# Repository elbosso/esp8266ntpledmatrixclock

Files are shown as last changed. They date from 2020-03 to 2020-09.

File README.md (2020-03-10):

# esp8266ntpledmatrixclock

<!---
[![start with why](https://img.shields.io/badge/start%20with-why%3F-brightgreen.svg?style=flat)](http://www.ted.com/talks/simon_sinek_how_great_leaders_inspire_action)
--->










This repository actually combines what i learned from building
https://github.com/elbosso/sonoffSocket
and 
https://github.com/elbosso/esp8266epaperdoorsign
with an MAX7119 8x8 Led Matrix (well - actually four of them) and
a photo resistor.

The data for connecting with your wifi is located in a header file named `wifi_security.h` that i did
not commit for obvious reasons. Its contents look something like the contents of the example named
`wifi_security_h.example`:

```
#ifndef WIFISECURITY_H
#define WIFISECURITY_H

char wifi_ssid[]="<wifi_ssid>";
char wifi_pwd[]="<wifi_pwd>";
char wifi_ssid_cell_ap[]="<wifi_ssid_cell_ap>";
char wifi_pwd_cell_ap[]="<wifi_pwd_cell_ap>";

#endif /* WIFISECURITY_H */
```

The define `AT_HOME` is used to control what NTP-server should be used: The source code presumes a local NTP-server 
exists at IP-address `192.168.10.2` if
`AT_HOME` is set to 1 - if this is not so, it currently asks `2.de.pool.ntp.org` for the time.

The define `AT_HOME` also decides which pair of WIFI credentials are to be used.

Instructions for setting up the arduino IDE to actually be able to transfer the code to a Wemos D1 (clone) can be found [here](https://averagemaker.com/2018/03/wemos-d1-mini-setup.html)

And so we have a nifty little clock...

## Important Update

This project continues the work originally started in this project: https://github.com/elbosso/ESP8266-WiFi-Marquee

The new features include:

* offering a HTTP interface for specifying arbitrary text that is displayed using running text
* offering an MQTT interface for the same reasons
* allowing to switch the display of the time on and off both via HTTP and MQTT
* possibility to use arbitrarily many chained display modules

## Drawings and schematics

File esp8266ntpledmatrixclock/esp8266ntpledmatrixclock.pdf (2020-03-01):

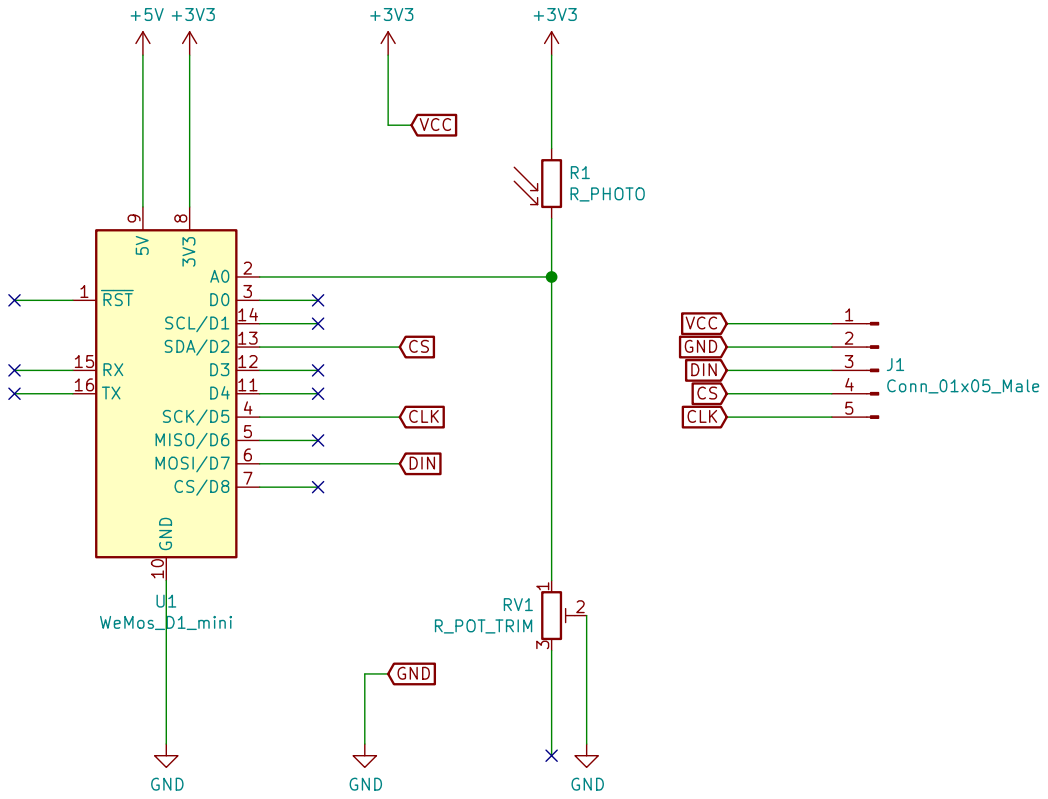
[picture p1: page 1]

File: esp8266ntpledmatrixclock.sch Sheet: / GND

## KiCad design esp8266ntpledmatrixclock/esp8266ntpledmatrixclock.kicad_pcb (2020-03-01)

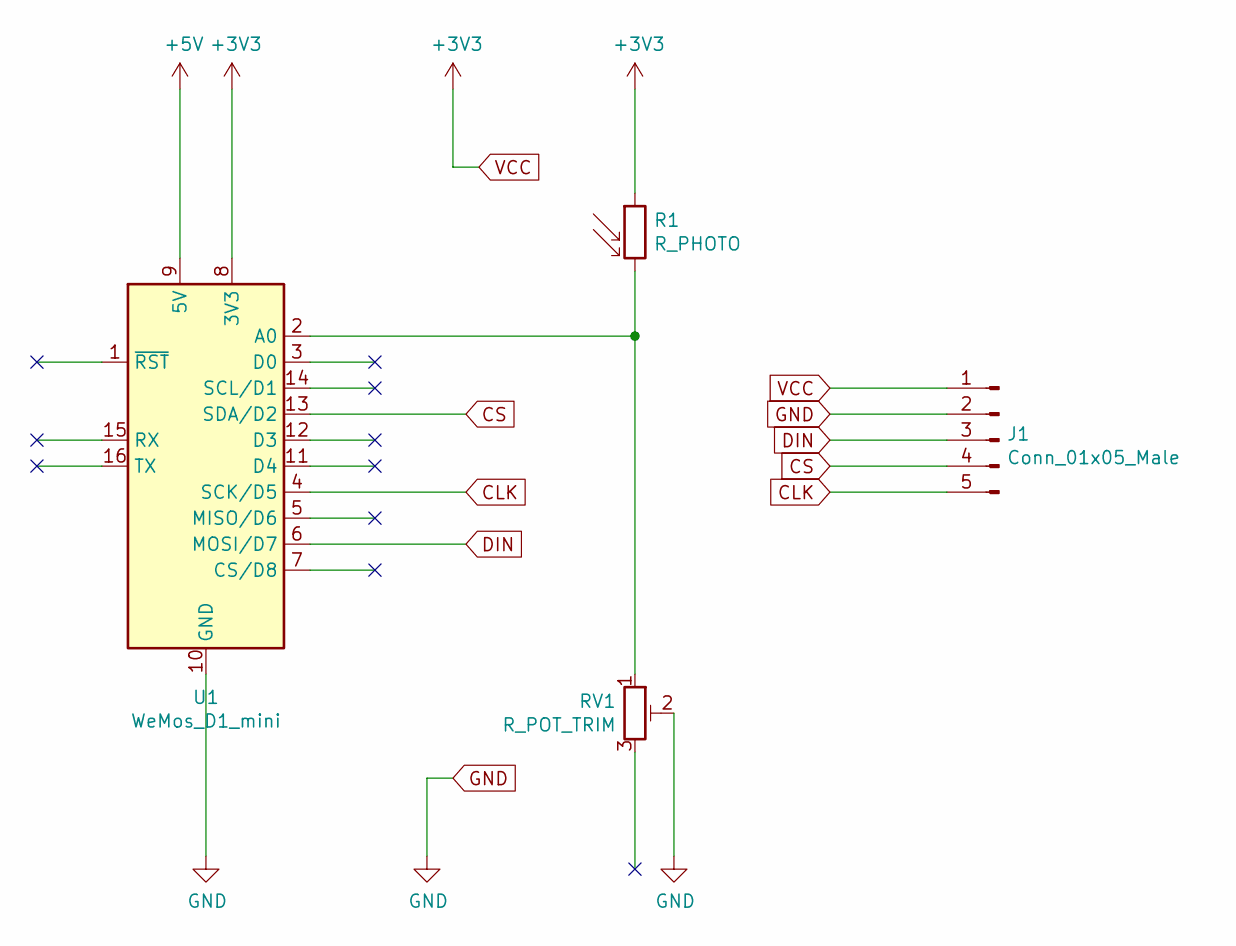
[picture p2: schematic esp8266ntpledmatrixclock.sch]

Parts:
J1: Conn_01x05_Male; PinHeader_1x05_P2.54mm_Vertical
R1: R_PHOTO; R_Axial_DIN0309_L9.0mm_D3.2mm_P12.70mm_Horizontal
RV1: R_POT_TRIM; Potentiometer_Bourns_3386F_Vertical
U1: WeMos_D1_mini; WEMOS_D1_mini_light

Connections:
+5V: U1.9 (5V)
CLK: J1.5, U1.4 (SCK/D5)
CS: J1.4, U1.13 (SDA/D2)
DIN: J1.3, U1.6 (MOSI/D7)
GND: J1.2, RV1.2, U1.10 (GND)
unnamed: R1.2, RV1.1, U1.2 (A0)
VCC: J1.1, R1.1, U1.8 (3V3)

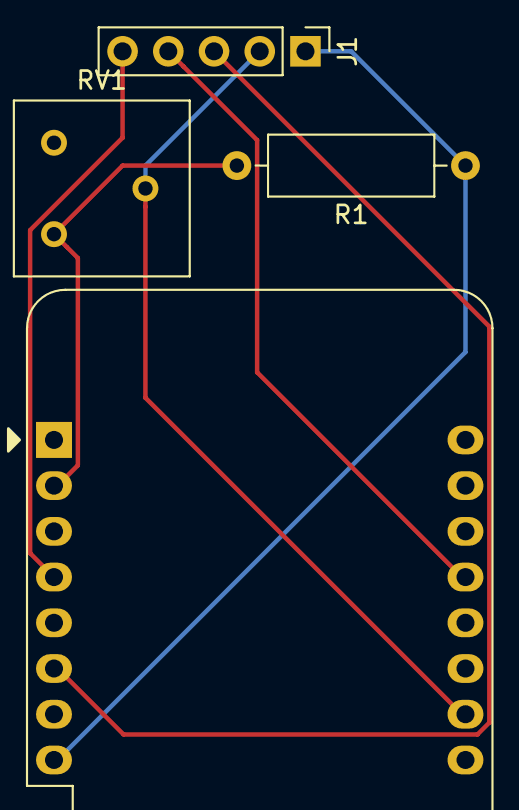
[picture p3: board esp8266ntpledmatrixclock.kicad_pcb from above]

Board: 2 copper layers, 4 parts (0 on the bottom side), 6 nets.

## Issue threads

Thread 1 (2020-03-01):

daisy-chain more than one display and make it possible to display short messages via mqtt or http

elbosso, 2020-03-01:

elbosso, 2020-03-10:
done!

Closed 2020-03-10.

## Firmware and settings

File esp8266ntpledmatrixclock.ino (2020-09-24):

/*
  Copyright (c) 2018.

  Juergen Key. Alle Rechte vorbehalten.

  Weiterverbreitung und Verwendung in nichtkompilierter oder kompilierter Form,
  mit oder ohne Veraenderung, sind unter den folgenden Bedingungen zulaessig:

   1. Weiterverbreitete nichtkompilierte Exemplare muessen das obige Copyright,
  die Liste der Bedingungen und den folgenden Haftungsausschluss im Quelltext
  enthalten.
   2. Weiterverbreitete kompilierte Exemplare muessen das obige Copyright,
  die Liste der Bedingungen und den folgenden Haftungsausschluss in der
  Dokumentation und/oder anderen Materialien, die mit dem Exemplar verbreitet
  werden, enthalten.
   3. Weder der Name des Autors noch die Namen der Beitragsleistenden
  duerfen zum Kennzeichnen oder Bewerben von Produkten, die von dieser Software
  abgeleitet wurden, ohne spezielle vorherige schriftliche Genehmigung verwendet
  werden.

  DIESE SOFTWARE WIRD VOM AUTOR UND DEN BEITRAGSLEISTENDEN OHNE
  JEGLICHE SPEZIELLE ODER IMPLIZIERTE GARANTIEN ZUR VERFUEGUNG GESTELLT, DIE
  UNTER ANDEREM EINSCHLIESSEN: DIE IMPLIZIERTE GARANTIE DER VERWENDBARKEIT DER
  SOFTWARE FUER EINEN BESTIMMTEN ZWECK. AUF KEINEN FALL IST DER AUTOR
  ODER DIE BEITRAGSLEISTENDEN FUER IRGENDWELCHE DIREKTEN, INDIREKTEN,
  ZUFAELLIGEN, SPEZIELLEN, BEISPIELHAFTEN ODER FOLGENDEN SCHAEDEN (UNTER ANDEREM
  VERSCHAFFEN VON ERSATZGUETERN ODER -DIENSTLEISTUNGEN; EINSCHRAENKUNG DER
  NUTZUNGSFAEHIGKEIT; VERLUST VON NUTZUNGSFAEHIGKEIT; DATEN; PROFIT ODER
  GESCHAEFTSUNTERBRECHUNG), WIE AUCH IMMER VERURSACHT UND UNTER WELCHER
  VERPFLICHTUNG AUCH IMMER, OB IN VERTRAG, STRIKTER VERPFLICHTUNG ODER
  UNERLAUBTE HANDLUNG (INKLUSIVE FAHRLAESSIGKEIT) VERANTWORTLICH, AUF WELCHEM
  WEG SIE AUCH IMMER DURCH DIE BENUTZUNG DIESER SOFTWARE ENTSTANDEN SIND, SOGAR,
  WENN SIE AUF DIE MOEGLICHKEIT EINES SOLCHEN SCHADENS HINGEWIESEN WORDEN SIND.
*/

#define AT_HOME 1
#define REGELBETRIEB 1

#include <FS.h> //this needs to be first, or it all crashes and burns...

#include <ESP8266WiFi.h>
#include <WiFiClient.h>
#include <ESP8266WebServer.h>
#include <ESP8266mDNS.h>
#include <WiFiUdp.h>
//needed for wifimanager
#include <DNSServer.h>
#include <WiFiManager.h>          //https://github.com/tzapu/WiFiManager
#include <PubSubClient.h>
#include "RemoteDebug.h"  //https://github.com/JoaoLopesF/RemoteDebug

//
// Debug messages over the serial console.
//
#include "debug.h"

#include <NTPClient.h>
#include <WiFiUdp.h>
#include <TimeLib.h>
#include <Timezone.h>    // https://github.com/JChristensen/Timezone
#include <stdio.h>
#include <user_interface.h>
#include <ArduinoJson.h>          // https://github.com/bblanchon/ArduinoJson
#include <LEDMatrixDriver.hpp>
#include "wifi_security.h"
#include "clock_font.h"
#include "marquee_font.h"
#include "marquee_font1.h"
#include "marquee_form.h"

/**
  Random Number Generator 32bit
  http://esp8266-re.foogod.com/wiki/Random_Number_Generator
 **/
#define RANDOM_REG32  ESP8266_DREG(0x20E44)
 
//ESP8266WebServer* server;
ESP8266WebServer marqueeserver(8080);  // HTTP server will listen at port 8080

bool lamp = 0;

char port[6] = "80";

//flag for saving data
bool shouldSaveConfig = false;

int gpio0Switch = 5;

unsigned long previousMillis = 0;

boolean bold=false;

WiFiUDP ntpUDP;

// By default 'pool.ntp.org' is used with 60 seconds update interval and
// no offset
#ifdef AT_HOME
const char* NTP_SERVER = "192.168.10.2";
#else
const char* NTP_SERVER = "2.de.pool.ntp.org";
#endif

NTPClient timeClient(ntpUDP, NTP_SERVER);

// You can specify the time server pool and the offset, (in seconds)
// additionaly you can specify the update interval (in milliseconds).
// NTPClient timeClient(ntpUDP, "europe.pool.ntp.org", 3600, 60000);

// Central European Time (Frankfurt, Paris)
TimeChangeRule CEST = {"CEST", Last, Sun, Mar, 2, 120};     // Central European Summer Time
TimeChangeRule CET = {"CET ", Last, Sun, Oct, 3, 60};       // Central European Standard Time
Timezone CE(CEST, CET);

// Define the ChipSelect pin for the led matrix (Dont use the SS or MISO pin of your Arduino!)
// Other pins are arduino specific SPI pins (MOSI=DIN of the LEDMatrix and CLK) see https://www.arduino.cc/en/Reference/SPI
//https://github.com/esp8266/Arduino/issues/1243
const uint8_t LEDMATRIX_CS_PIN = 4;

// Define LED Matrix dimensions (0-n) - eg: 32x8 = 31x7
const int LEDMATRIX_WIDTH = 63;  
const int LEDMATRIX_HEIGHT = 7;
const int LEDMATRIX_SEGMENTS = (LEDMATRIX_WIDTH+1)/8;

// The LEDMatrixDriver class instance
LEDMatrixDriver lmd(LEDMATRIX_SEGMENTS, LEDMATRIX_CS_PIN);

int intensity=0;

int x=0, y=0;   // start top left


// Marquee speed
const int ANIM_DELAY = 60;

char lcdBuf[5];
char lcdBufOld[5];
char timestrbuf[100];

unsigned int counter=0;

char oben[2];
char unten[2];

char fixed[5];
char moving[6];
char mnew[5];

char emm[]="M";

int animcounter;
int animationmode;

int loopcounter=95;

String decodedMsg;
String msg;
int wait = 75; // In milliseconds

int spacer = 2;
int width = 5 + spacer; // The font width is 5 pixels
int maxRuns=1;
int runs=0;

long period;
int offset=1,refresh=0;

bool shouldDisplayClock = true;
bool shouldDisplay = true;

const char* MQTT_BROKER = "mqtt.pi-docker.lab";
WiFiClient espClient;
PubSubClient client(espClient);

RemoteDebug Debug;

//callback notifying us of the need to save config
void saveConfigCallback ()
{
  Serial.println("Should save config");
  shouldSaveConfig = true;
}


void setup(void)
{
  randomSeed(RANDOM_REG32);
  animationmode=random(0,5);
  animcounter=random(0,100);
  rst_info *resetInfo;
  resetInfo = ESP.getResetInfoPtr();
  Serial.begin(115200);
  // delay(5000);
  //  Serial.println("");
  //clean FS, for testing
  //SPIFFS.format();
  pinMode(gpio0Switch, INPUT_PULLUP); // Push Button for GPIO0 active LOW

  // init the display
  lmd.setEnabled(true);
  lmd.setIntensity(intensity);   // 0 = low, 10 = high

  String realSize = String(ESP.getFlashChipRealSize());
  String ideSize = String(ESP.getFlashChipSize());
  bool flashCorrectlyConfigured = realSize.equals(ideSize);

  //read configuration from FS json
  Serial.println("mounting FS...");

  //  if(flashCorrectlyConfigured)
  {
    if (SPIFFS.begin())
    {
      Serial.println("mounted file system");
      if (SPIFFS.exists("/config.json"))
      {
        //file exists, reading and loading
        Serial.println("reading config file");
        File configFile = SPIFFS.open("/config.json", "r");
        if (configFile)
        {
          Serial.println("opened config file");
          size_t size = configFile.size();
          // Allocate a buffer to store contents of the file.
          std::unique_ptr<char[]> buf(new char[size]);

          configFile.readBytes(buf.get(), size);
          DynamicJsonBuffer jsonBuffer;
          JsonObject& json = jsonBuffer.parseObject(buf.get());
          json.printTo(Serial);
          if (json.success())
          {
            Serial.println("\nparsed json");
/*            strcpy(port, json["port"]);
            strcpy(host, json["host"]);
            strcpy(path, json["path"]);
*/          }
          else
          {
            Serial.println("failed to load json config");
          }
        }
      }
    }
    else
    {
      Serial.println("failed to mount FS");
    }
    //end read
  }
  //  else
  //    else Serial.println("flash incorrectly configured, SPIFFS cannot start, IDE size: " + ideSize + ", real size: " + realSize);



  WiFi.persistent(true);
  WiFi.mode(WIFI_OFF);
  WiFi.mode(WIFI_STA);
#ifdef REGELBETRIEB
  Serial.println(digitalRead(gpio0Switch) == HIGH ? "HIGH" : "LOW");
  if (digitalRead(gpio0Switch) == HIGH)
    WiFi.begin(WiFi.SSID().c_str(), WiFi.psk().c_str()); // reading data from EPROM, (last saved credentials)
  else
  {
    WiFi.persistent(false);
    WiFi.begin("geht", "nicht");
    WiFi.persistent(true);
  }
#else
#ifdef AT_HOME
  WiFi.begin(wifi_ssid,wifi_pwd); // reading data from EPROM, (last saved credentials)
#else 
  WiFi.begin(wifi_ssid_cell_ap,wifi_pwd_cell_ap); // reading data from EPROM, (last saved credentials)
#endif
#endif
  pinMode(LED_BUILTIN, OUTPUT);
  digitalWrite(LED_BUILTIN, lamp);

  // Wait for WiFi
  Serial.println("");
  Serial.print("Verbindungsaufbau mit:  ");
  Serial.println(WiFi.SSID().c_str());

  while (WiFi.status() == WL_DISCONNECTED)            // last saved credentials
  {
    delay(500);
    if (lamp == 0)
    {
      digitalWrite(LED_BUILTIN, 1);
      lamp = 1;
    }
    else
    {
      digitalWrite(LED_BUILTIN, 0);
      lamp = 0;
    }
    Serial.print(".");
  }
  lamp = 0;
  digitalWrite(LED_BUILTIN, 0);

  wl_status_t status = WiFi.status();
  if (status == WL_CONNECTED)
  {
    Serial.printf("\nConnected successful to SSID '%s'\n", WiFi.SSID().c_str());
  }
  else
  {
    WiFi.mode(WIFI_OFF);
    //WiFiManager
    //Local intialization. Once its business is done, there is no need to keep it around
    WiFiManager wifiManager;
    //set config save notify callback
    wifiManager.setSaveConfigCallback(saveConfigCallback);

/*    WiFiManagerParameter custom_port("Port", "Port", port, 5);
    WiFiManagerParameter custom_host("Host", "Host", host, 99);
    WiFiManagerParameter custom_path("Path", "Path", path, 99);
    wifiManager.addParameter(&custom_port);
    wifiManager.addParameter(&custom_host);
    wifiManager.addParameter(&custom_path);
*/
    //reset settings - for testing
    //wifiManager.resetSettings();

    //sets timeout until configuration portal gets turned off
    //useful to make it all retry or go to sleep
    //in seconds
    digitalWrite(LED_BUILTIN, LOW);

    //fetches ssid and pass and tries to connect
    //if it does not connect it starts an access point with the specified name
    //here  "AutoConnectAP_12F647"
    //and goes into a blocking loop awaiting configuration
    if (!wifiManager.autoConnect("AutoConnectAP_ntplmc"))
    {
      WiFi.mode(WIFI_OFF);
      WiFi.mode(WIFI_STA);
      digitalWrite(LED_BUILTIN, HIGH);
      // WPS button I/O setup
      /*      Serial.printf("\nCould not connect to WiFi. state='%d'\n", status);
            Serial.println("Please press WPS button on your router, until mode is indicated.");
            Serial.println("next press the ESP module WPS button, router WPS timeout = 2 minutes");

            while(digitalRead(gpio0Switch) == HIGH)  // wait for WPS Button active
            {
              delay(50);
              if(lamp == 0){
                 digitalWrite(LED_BUILTIN, 1);
                 lamp = 1;
               }else{
                 digitalWrite(LED_BUILTIN, 0);
                 lamp = 0;
              }
              Serial.print(".");
              yield(); // do nothing, allow background work (WiFi) in while loops
            }
            Serial.println("WPS button pressed");
            lamp=0;
            digitalWrite(LED_BUILTIN, 0);

            if(!startWPSPBC()) {
               Serial.println("Failed to connect with WPS :-(");
            } else*/
      {
        WiFi.begin(WiFi.SSID().c_str(), WiFi.psk().c_str()); // reading data from EPROM,
        while (WiFi.status() == WL_DISCONNECTED)            // last saved credentials
        {
          delay(500);
          Serial.print("."); // show wait for connect to AP
        }
      }
    }
    else
    {
  /*    Serial.println(custom_port.getValue());
      Serial.println(custom_host.getValue());
      Serial.println(custom_path.getValue());
      strcpy(port, custom_port.getValue());
      strcpy(host, custom_host.getValue());
      strcpy(path, custom_path.getValue());
*/
      //save the custom parameters to FS
      if (shouldSaveConfig)
      {
        Serial.println("saving config");
        DynamicJsonBuffer jsonBuffer;
        JsonObject& json = jsonBuffer.createObject();
/*        json["host"] = host;
        json["port"] = port;
        json["path"] = path;
*/
        File configFile = SPIFFS.open("/config.json", "w");
        if (!configFile)
        {
          Serial.println("failed to open config file for writing");
        }

        json.printTo(Serial);
        json.printTo(configFile);
        configFile.close();
        //end save
      }

    }
  }
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
void loop(void)
{
  #ifdef AT_HOME
    if (!client.connected()) {
        reconnect();
    }
    client.loop();
  #endif
  ++loopcounter;
  sprintf(lcdBufOld,"%s",lcdBuf);
  timeClient.update();
  Debug.println(timeClient.getFormattedTime());
  unsigned long epoch = timeClient.getEpochTime();
//  Serial.println(epoch);

  TimeChangeRule *tcr;
  time_t utc;
  utc = epoch;

  time_t local = CE.toLocal(utc, &tcr);
//  Serial.println(local);

  unsigned long h = hour(local);
  unsigned long mi = minute(local);
  unsigned long s = second(local);
  unsigned long y = year(local);
  unsigned long mo = month(local);
  unsigned long d = day(local);

//  Serial.print("local: ");
  printTimeToBuffer(local, tcr -> abbrev);
//  Serial.println(timestrbuf);
  printTimeToLCDBuffer(local, tcr -> abbrev);
  lcdBuf[1]=lcdBuf[1]-15;
//  sprintf(lcdBuf, "%04d", ++counter);
  int changeDetected=0;
//  animationmode=1;
  //5:horizontal shrink, vertical grow
  //4:vertical shrink, vertical grow
  //3:vertical shrink, horizontal grow
  //2:horizontal shrink, horizontal grow
  //1:shift out to right, shift in from right
  //default:roll from top
  if((shouldDisplayClock==true)&&(shouldDisplay==true))
  {
  switch(animationmode)
  {
    case 5: //5:horizontal shrink, vertical grow
    {
      int decimal=5;
      for(int i=0;i<4;++i)
      {
        if(lcdBufOld[i]!=lcdBuf[i])
        {
          changeDetected=1;
          for(int j=3;j>=i;--j)
          {
            int jj=j+(LEDMATRIX_WIDTH+1-32)/2/8;
            for(int k=0;k<4;++k)
            {
              if(k<j)
              {
                fixed[k]=lcdBufOld[k];
              }
              else
              {
                moving[k-j]=lcdBufOld[k];
                moving[k-j+1]=0;
                mnew[k-j]=lcdBuf[k];
                mnew[k-j+1]=0;
                fixed[k]=0;
              }
            }
            byte* sprite=clockfont[moving[0]- 32];
            byte* newsprite=clockfont[mnew[0]- 32];
            byte* destination=clockfont['M'- 32];
            for(int l=0;l<4;++l)
            {
              for(int m=0;m<8;++m)
              {
                destination[m]=(sprite [m]>>l)&0xF0;
                destination[m]=destination[m]|((sprite [m]<<l)&0x0F);
              }
              drawClockString(fixed, i, (s%2)+(LEDMATRIX_WIDTH+1-32)/2, 0);
              drawClockString(emm, 1, (s%2)+(jj)*8, 0);
              lmd.display();
     marqueeserver.handleClient();   // checks for incoming messages
              delay(ANIM_DELAY*2);
            }
            for(int l=4;l>0;--l)
            {
              for(int m=0;m<8;++m)
              {
                destination[m]=newsprite[m];
              }
              for(int m=1;m<l;++m)
              {
                destination[m+1]|=destination[m];
                destination[m]=0;
                destination[7-m]|=destination[7-m+1];
                destination[7-m+1]=0;
              }
              drawClockString(fixed, i, (s%2)+16, 0);
              drawClockString(emm, 1, (s%2)+(jj)*8, 0);
              lmd.display();
    marqueeserver.handleClient();   // checks for incoming messages
             delay(ANIM_DELAY*2);
            }
          }
          break;    
        }
      }
      break;
    }
    case 4://4:vertical shrink, vertical grow
    {
      int decimal=5;
      for(int i=0;i<4;++i)
      {
        if(lcdBufOld[i]!=lcdBuf[i])
        {
          changeDetected=1;
          for(int j=3;j>=i;--j)
          {
            int jj=j+(LEDMATRIX_WIDTH+1-32)/2/8;
            for(int k=0;k<4;++k)
            {
              if(k<j)
              {
                fixed[k]=lcdBufOld[k];
              }
              else
              {
                moving[k-j]=lcdBufOld[k];
                moving[k-j+1]=0;
                mnew[k-j]=lcdBuf[k];
                mnew[k-j+1]=0;
                fixed[k]=0;
              }
            }
            byte* sprite=clockfont[moving[0]- 32];
            byte* newsprite=clockfont[mnew[0]- 32];
            byte* destination=clockfont['M'- 32];
            for(int m=0;m<8;++m)
            {
              destination[m]=sprite [m];
            }
            for(int l=1;l<4;++l)
            {
              destination[l+1]|=destination[l];
              destination[l]=0;
              destination[7-l]|=destination[7-l+1];
              destination[7-l+1]=0;
              drawClockString(fixed, i, (s%2)+(LEDMATRIX_WIDTH+1-32)/2, 0);
              drawClockString(emm, 1, (s%2)+(jj)*8, 0);
              lmd.display();
    marqueeserver.handleClient();   // checks for incoming messages
             delay(ANIM_DELAY*2);
            }
            for(int l=4;l>0;--l)
            {
              for(int m=0;m<8;++m)
              {
                destination[m]=newsprite[m];
              }
              for(int m=1;m<l;++m)
              {
                destination[m+1]|=destination[m];
                destination[m]=0;
                destination[7-m]|=destination[7-m+1];
                destination[7-m+1]=0;
              }
              drawClockString(fixed, i, (s%2)+(LEDMATRIX_WIDTH+1-32)/2, 0);
              drawClockString(emm, 1, (s%2)+(jj)*8, 0);
              lmd.display();
    marqueeserver.handleClient();   // checks for incoming messages
             delay(ANIM_DELAY*2);
            }
          }
          break;    
        }
      }
      break;
    }
    case 3://3:vertical shrink, horizontal grow
    {
      int decimal=5;
      for(int i=0;i<4;++i)
      {
        if(lcdBufOld[i]!=lcdBuf[i])
        {
          changeDetected=1;
          for(int j=3;j>=i;--j)
          {
            int jj=j+(LEDMATRIX_WIDTH+1-32)/2/8;
            for(int k=0;k<4;++k)
            {
              if(k<j)
              {
                fixed[k]=lcdBufOld[k];
              }
              else
              {
                moving[k-j]=lcdBufOld[k];
                moving[k-j+1]=0;
                mnew[k-j]=lcdBuf[k];
                mnew[k-j+1]=0;
                fixed[k]=0;
              }
            }
            byte* sprite=clockfont[moving[0]- 32];
            byte* newsprite=clockfont[mnew[0]- 32];
            byte* destination=clockfont['M'- 32];
            for(int m=0;m<8;++m)
            {
              destination[m]=sprite [m];
            }
            for(int l=1;l<4;++l)
            {
              destination[l+1]|=destination[l];
              destination[l]=0;
              destination[7-l]|=destination[7-l+1];
              destination[7-l+1]=0;
              drawClockString(fixed, i, (s%2)+(LEDMATRIX_WIDTH+1-32)/2, 0);
              drawClockString(emm, 1, (s%2)+(jj)*8, 0);
              lmd.display();
    marqueeserver.handleClient();   // checks for incoming messages
              delay(ANIM_DELAY*2);
            }
            for(int l=3;l>=0;--l)
            {
              for(int m=0;m<8;++m)
              {
                destination[m]=(newsprite [m]>>l)&0xF0;
                destination[m]=destination[m]|((newsprite [m]<<l)&0x0F);
              }
              drawClockString(fixed, i, (s%2)+(LEDMATRIX_WIDTH+1-32)/2, 0);
              drawClockString(emm, 1, (s%2)+(jj)*8, 0);
              lmd.display();
    marqueeserver.handleClient();   // checks for incoming messages
              delay(ANIM_DELAY*2);
            }
          }
          break;    
        }
      }
      break;
    }
    case 2://2:horizontal shrink, horizontal grow
    {
      int decimal=5;
      for(int i=0;i<4;++i)
      {
        if(lcdBufOld[i]!=lcdBuf[i])
        {
          changeDetected=1;
          for(int j=3;j>=i;--j)
          {
            int jj=j+(LEDMATRIX_WIDTH+1-32)/2/8;
            for(int k=0;k<4;++k)
            {
              if(k<j)
              {
                fixed[k]=lcdBufOld[k];
              }
              else
              {
                moving[k-j]=lcdBufOld[k];
                moving[k-j+1]=0;
                mnew[k-j]=lcdBuf[k];
                mnew[k-j+1]=0;
                fixed[k]=0;
              }
            }
            byte* sprite=clockfont[moving[0]- 32];
            byte* newsprite=clockfont[mnew[0]- 32];
            byte* destination=clockfont['M'- 32];
            for(int l=0;l<4;++l)
            {
              for(int m=0;m<8;++m)
              {
                destination[m]=(sprite [m]>>l)&0xF0;
                destination[m]=destination[m]|((sprite [m]<<l)&0x0F);
              }
              drawClockString(fixed, i, (s%2)+(LEDMATRIX_WIDTH+1-32)/2, 0);
              drawClockString(emm, 1, (s%2)+(jj)*8, 0);
              lmd.display();
    marqueeserver.handleClient();   // checks for incoming messages
              delay(ANIM_DELAY*2);
            }
            for(int l=3;l>=0;--l)
            {
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

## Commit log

2020-03-01 schematics added
    [esp8266ntpledmatrixclock.kicad_pcb, esp8266ntpledmatrixclock.sch]
2020-03-01 schematics added as pdf
2020-03-08 now one can display short messages on the display of the clock controlled by a web form the esp offers
    [esp8266ntpledmatrixclock.ino]
2020-03-09 now it is possible to switch of/switch on the clock display between messages from the html form all new features (scrolling messages, switching the clock display off and on) can now be used by sendin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
2020-03-10 new font for marquee - complete with lower case letters and umlauts
2020-03-10 failure to connect to mqtt broker no longer renders the clock useless...
    [esp8266ntpledmatrixclock.ino]
2020-03-10 problem with the persistent colon fixed
    [esp8266ntpledmatrixclock.ino]
2020-03-10 added value for resistor in voltage divider measuring ambient light
    [esp8266ntpledmatrixclock.sch]
2020-03-10 minor code cleanup, default is now a configuration with 8 8x8 ledmatrix modules in one line
2020-03-19 fixes #5, fixes #6
    [esp8266ntpledmatrixclock.ino]
2020-09-24 small bug fixed that influenced the command for switching off the display of the time: it would be switched off as soon as the minute changed
    [esp8266ntpledmatrixclock.ino]
